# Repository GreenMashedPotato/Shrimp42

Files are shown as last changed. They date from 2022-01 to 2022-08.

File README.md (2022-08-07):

# Shrimp42(previously Kibod-01) Work In Progress

it's a keyboard inspired by [Slepet](https://github.com/ibnuda/Slepet) that has more stagger in some columns and only 3 thumb cluster keys instead of 5.

## Rev 1 (initial prototype)
Non Mirrored Keyboard uses 1 pro micro with 2x5 10pin IDC Connector:
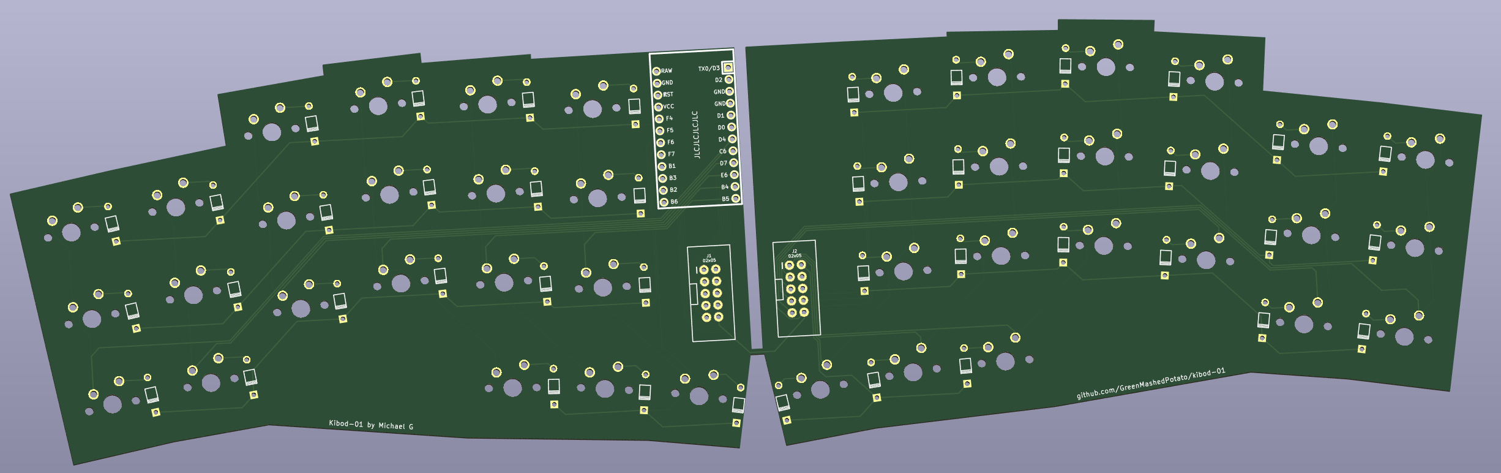
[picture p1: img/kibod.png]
kibod

 
Mirrored Keyboard, supports using 2 pro micros with trrs, or 1 pro micro with 2x5 10pin IDC Connector:
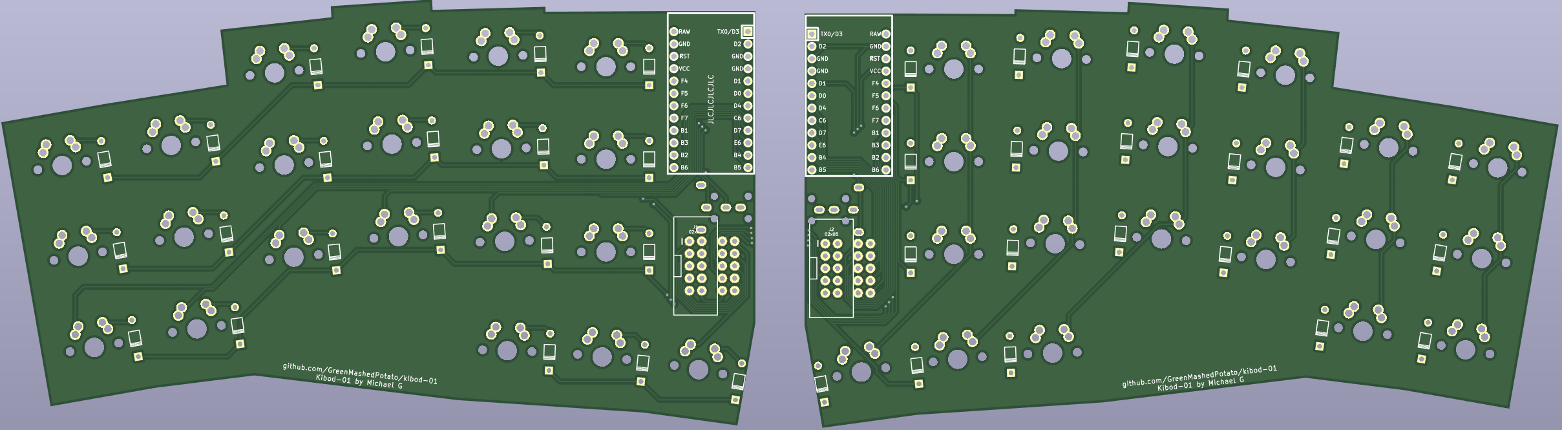
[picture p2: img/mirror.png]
mirror

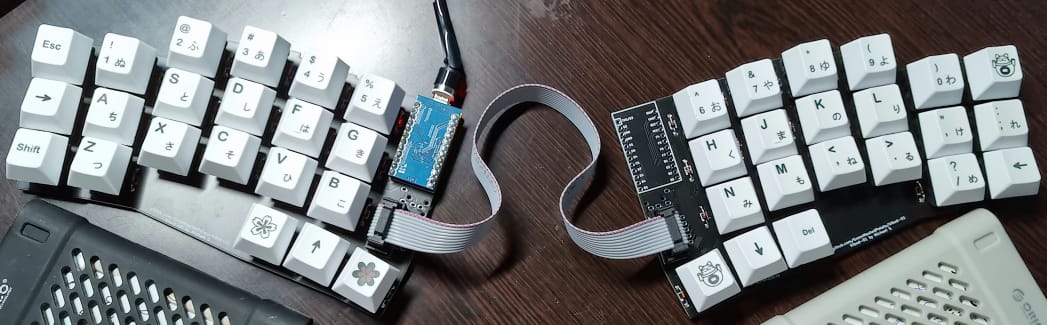
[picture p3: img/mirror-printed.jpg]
mirror


## Rev 2
Mirrored Keyboard Rev2(renamed to Shrimp42):
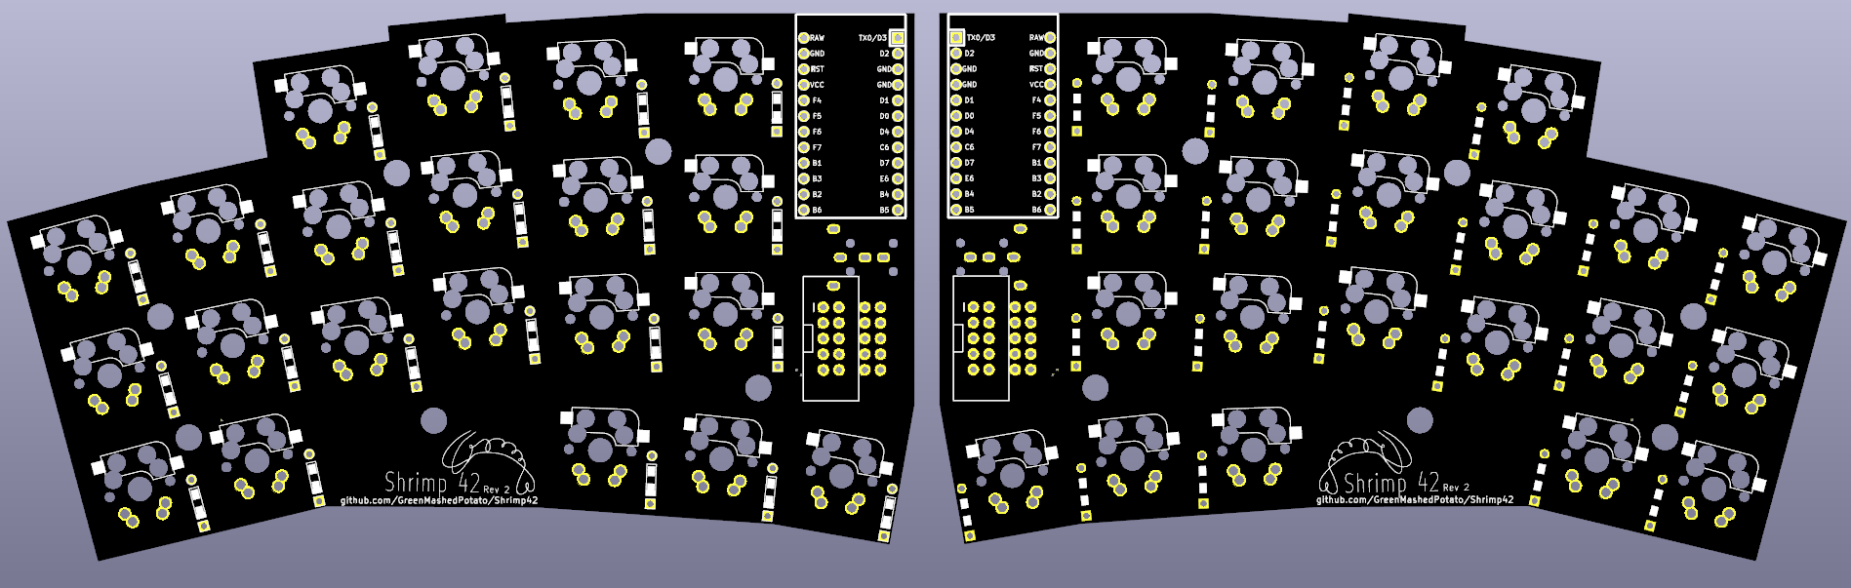
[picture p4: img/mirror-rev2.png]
mirror

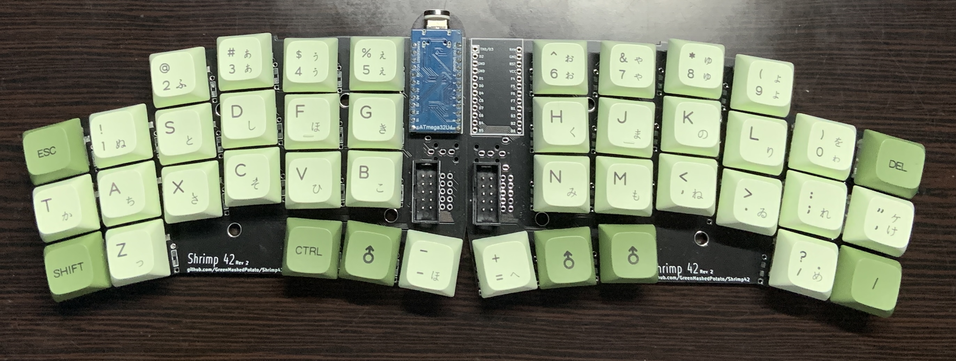
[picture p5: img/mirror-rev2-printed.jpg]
mirror

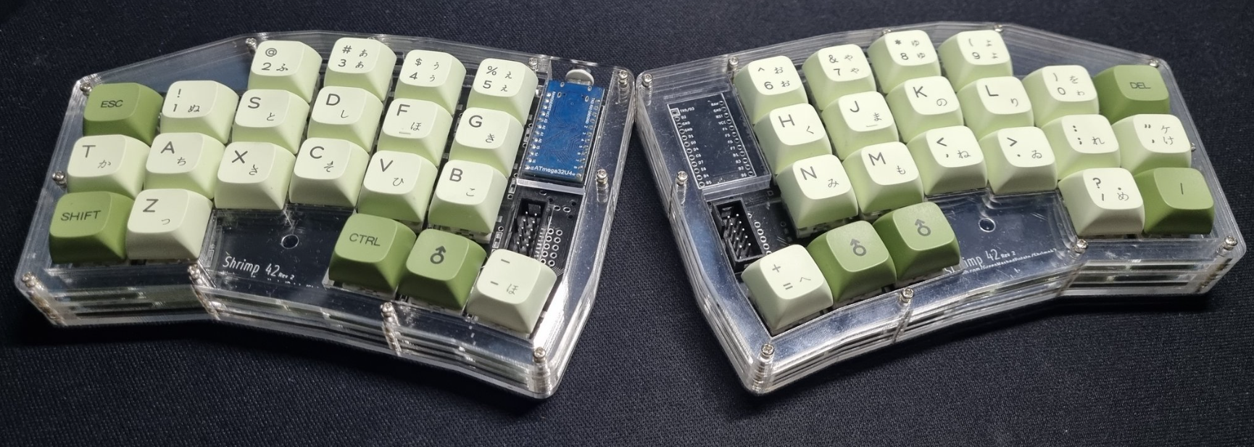
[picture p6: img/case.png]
case


improvements from rev1:

* adds support for hotswap sockets
* adds support for smd diodes
* changed angles from 2 to 3 degrees while reducing distance between columns. 
* add board name: Shrimp 42
* add Stacked Acrylic Case

V1 vs V2
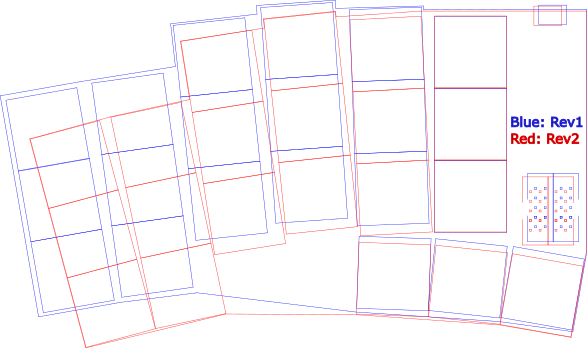
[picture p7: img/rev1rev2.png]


## Materials

| Qnty | Ref | Value | Description |
| --- | --- | --- | --- |
| 1 (2 if using trrs) | U1 | Arduino Pro-Micro ATmega32U4 |
| 42 | D-0-0 - D-3-5 | 1N4148 | Diode: 1N4148 (SOD 123 or THT)|
| 42 | K-0-0 - K-3-5 | MX or ALPS Switches | 1U |
| 42 (optional) | K-0-0 - K-3-5 | MX or ALPS Hotswap Sockets | this board supports the use of hotswap sockets and soldered connections |
| 2 | U2 | TRRS connectors OR 2x5 10pin IDC Connector |
| 1 | | TRRS Cable OR 2x5 10pin IDC Cable | used to connect both halves |
| 2 | | Shrimp42 pcb |
 
## Firmware
QMK and VIAL (provided via firmware but will need to sideload json and is untested) firmware for using the keyboard like in my setup above (using the extended GPIO pin to connect both halves and only 1 pro micro). [here](https://github.com/GreenMashedPotato/vial-qmk/tree/Shrimp42/keyboards/shrimp42).
 
QMK and VIAL for trrs connection (using 2 pro micros, slave board flipped, trrs connecting both sides) [here](https://github.com/GreenMashedPotato/vial-qmk/tree/Shrimp42/keyboards/shrimp42trrs)

## Library Used
[Keebio's footprints](https://github.com/keebio/Keebio-Parts.pretty)
[Ibnuda's footprints](https://github.com/ibnuda/rick-kicad-libs)

## Contact me:
Reddit [u/greenmashedpotato](https://www.reddit.com/user/greenmashedpotato)

## Disclaimer

I don't reccomend trying rev1 since the innermost and outermost column may be too far for some hands and can be tiring to use for long durations.

I haven't printed some of it. No guarantees that they work.

If things go wrong, I won't take any responisibilities, Try at your own risk.

## Additional Notes
After using the 2 in 1 diodes footprint, it may be too hard to know the orientation.
make sure the line on the diode is facing the square hole:
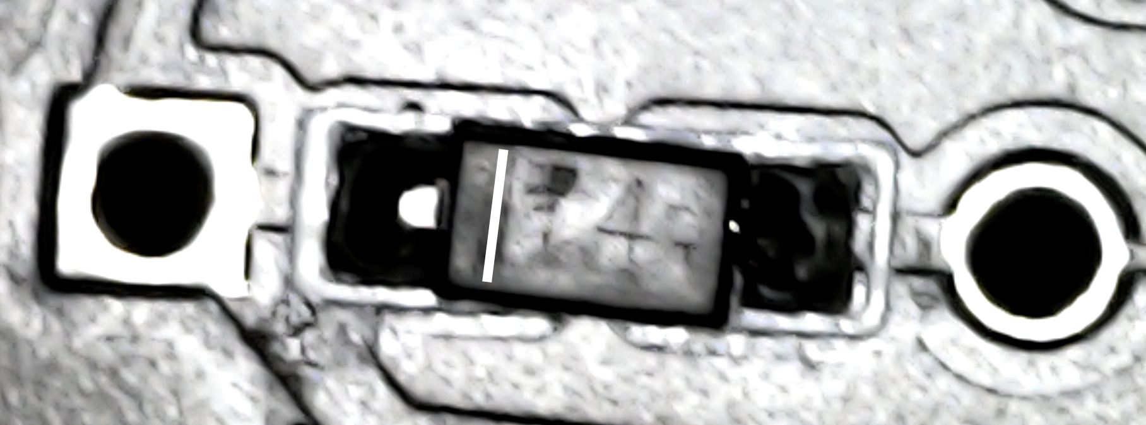
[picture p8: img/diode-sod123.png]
diode

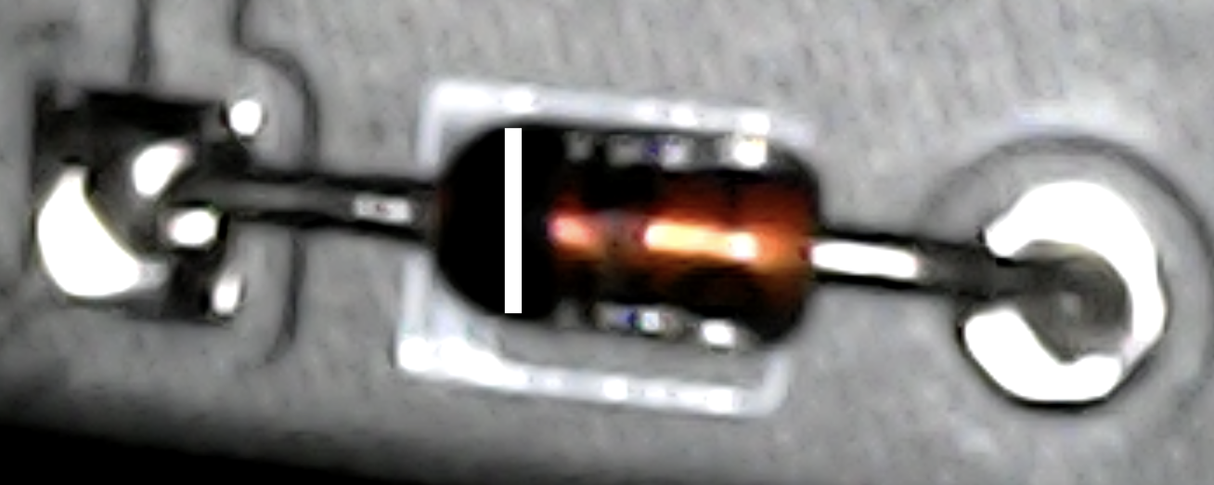
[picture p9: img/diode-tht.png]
diode


When using the Extended gpio pins to connect both halves, I have only tested using the pro micro on the left.

When using TRRS, dont forget to flip the right pro micro, I have only tested using the left pro micro as Master.

## License
GPL-3.0 License

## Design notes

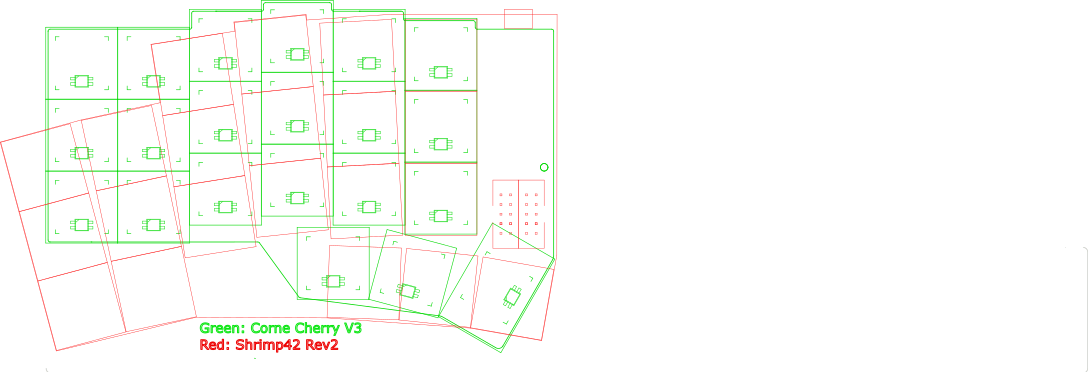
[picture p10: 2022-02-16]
img/shrimpvscorne.png

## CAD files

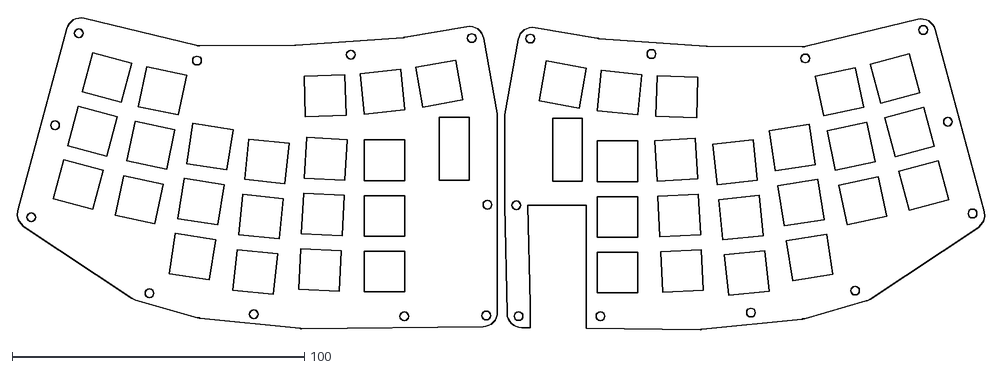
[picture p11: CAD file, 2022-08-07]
Case/Rev2/Acrylic Case/grouped by thickness/1.5mm group.dxf
331.9 x 107.2

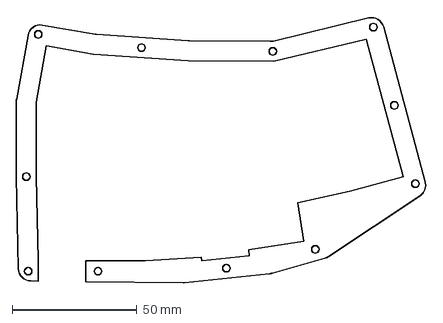
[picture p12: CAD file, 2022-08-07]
Case/Rev2/Acrylic Case/individual/middle left 2 4mm.dxf
164.7 x 106.8 mm

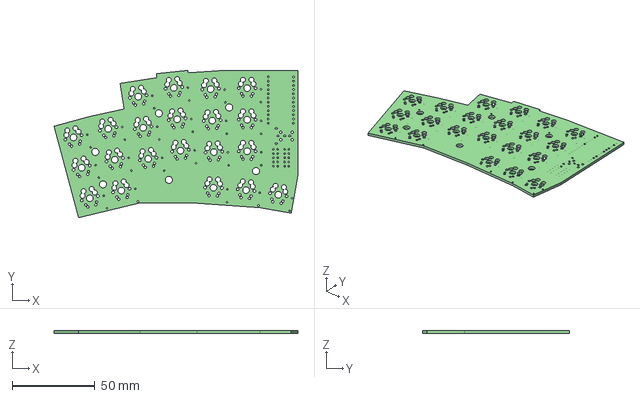
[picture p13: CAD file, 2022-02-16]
Rev2/Mirrored Rev2/kibod-01.step
147.3 x 89.0 x 1.60 mm

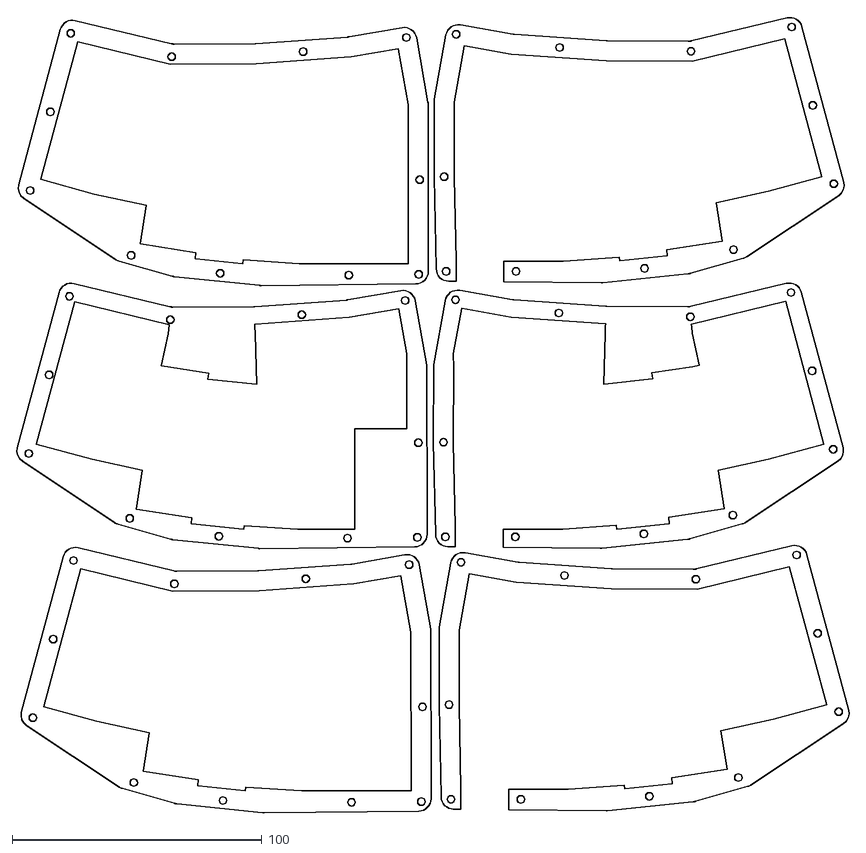
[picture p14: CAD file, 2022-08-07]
Case/Rev2/Acrylic Case/grouped by thickness/4mm group.dxf
334.3 x 319.2

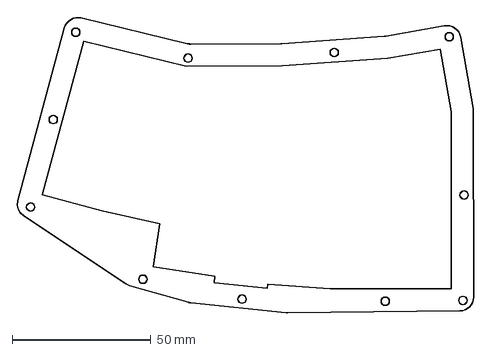
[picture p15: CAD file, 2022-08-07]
Case/Rev2/Acrylic Case/individual/middle right 4mm.dxf
164.7 x 106.8 mm

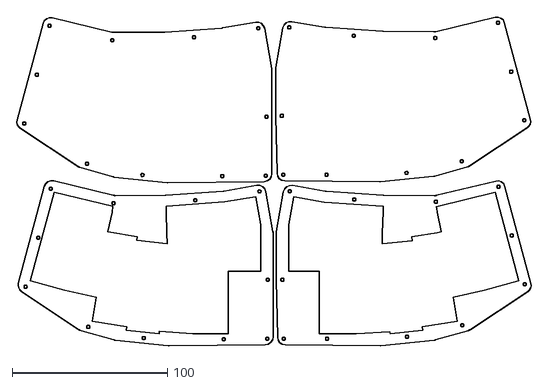
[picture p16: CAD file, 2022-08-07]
Case/Rev2/Acrylic Case/grouped by thickness/3mm group.dxf
332.3 x 212.5

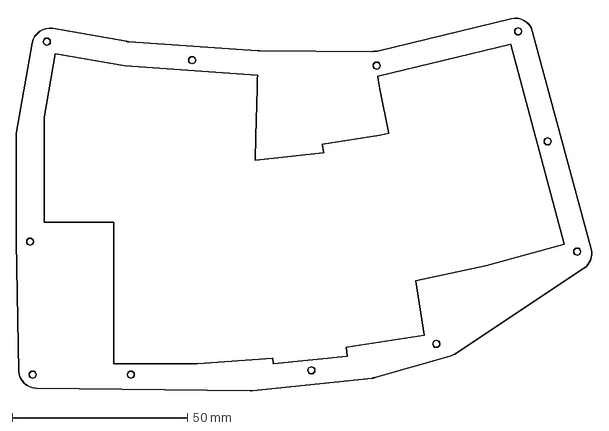
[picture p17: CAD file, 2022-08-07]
Case/Rev2/Acrylic Case/individual/top left 3mm.dxf
164.7 x 106.8 mm

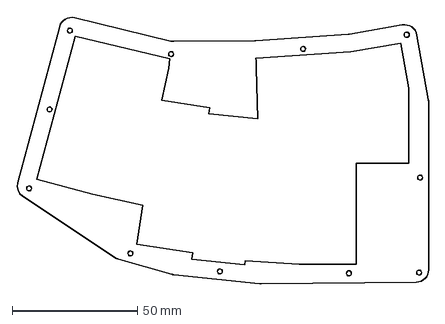
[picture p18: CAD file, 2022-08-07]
Case/Rev2/Acrylic Case/individual/top right 3mm.dxf
164.7 x 106.8 mm

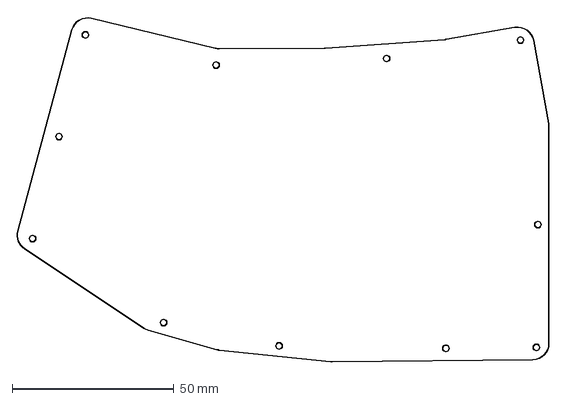
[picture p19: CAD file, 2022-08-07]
Case/Rev2/Acrylic Case/individual/bottom right 3mm.dxf
164.7 x 106.8 mm

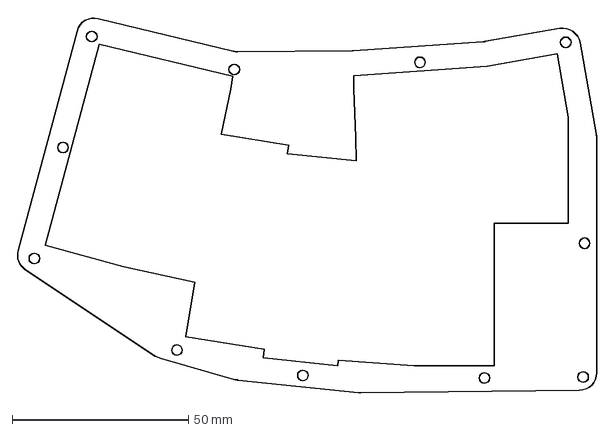
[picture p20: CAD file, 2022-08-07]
Case/Rev2/Acrylic Case/individual/second right 4mm.dxf
164.7 x 106.8 mm

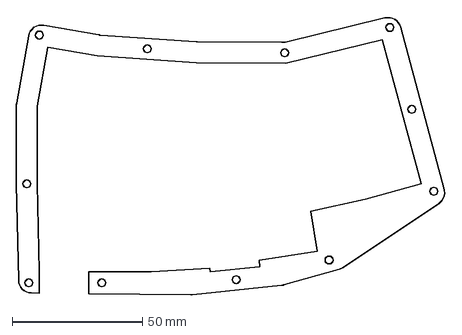
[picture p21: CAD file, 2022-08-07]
Case/Rev2/Acrylic Case/individual/middle left 4mm.dxf
164.7 x 106.8 mm

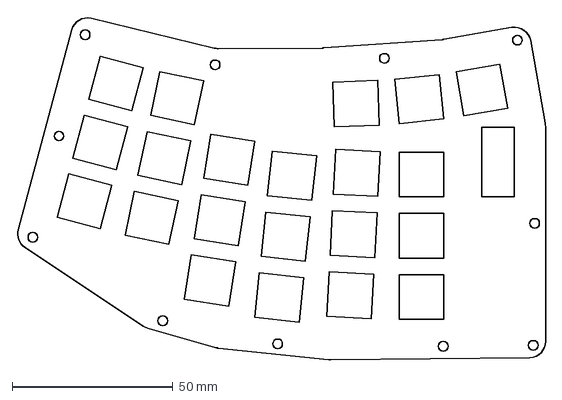
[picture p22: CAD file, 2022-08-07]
Case/Rev2/Acrylic Case/individual/plate right 1.5mm.dxf
164.7 x 106.8 mm

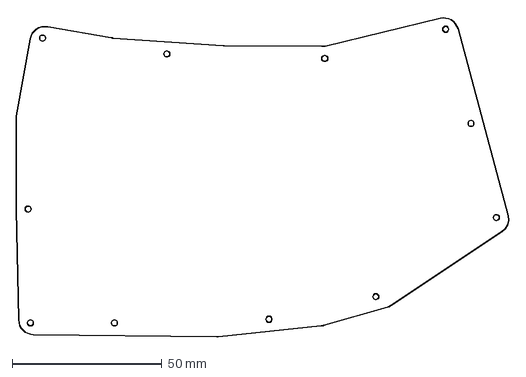
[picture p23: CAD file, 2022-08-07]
Case/Rev2/Acrylic Case/individual/bottom left 3mm.dxf
164.7 x 106.8 mm

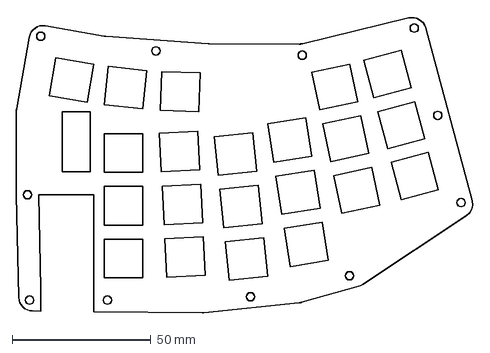
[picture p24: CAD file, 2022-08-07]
Case/Rev2/Acrylic Case/individual/plate left 1.5mm.dxf
164.7 x 106.8 mm

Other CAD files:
Case/Rev2/Acrylic Case/individual/second left 4mm.dxf
Case/Rev2/Acrylic Case/individual/middle right 2 4mm.dxf
Rev1/Mirrored Rev1/kibod-01-mirrored.step
Rev1/non-mirrored Rev1/kibod-01.step

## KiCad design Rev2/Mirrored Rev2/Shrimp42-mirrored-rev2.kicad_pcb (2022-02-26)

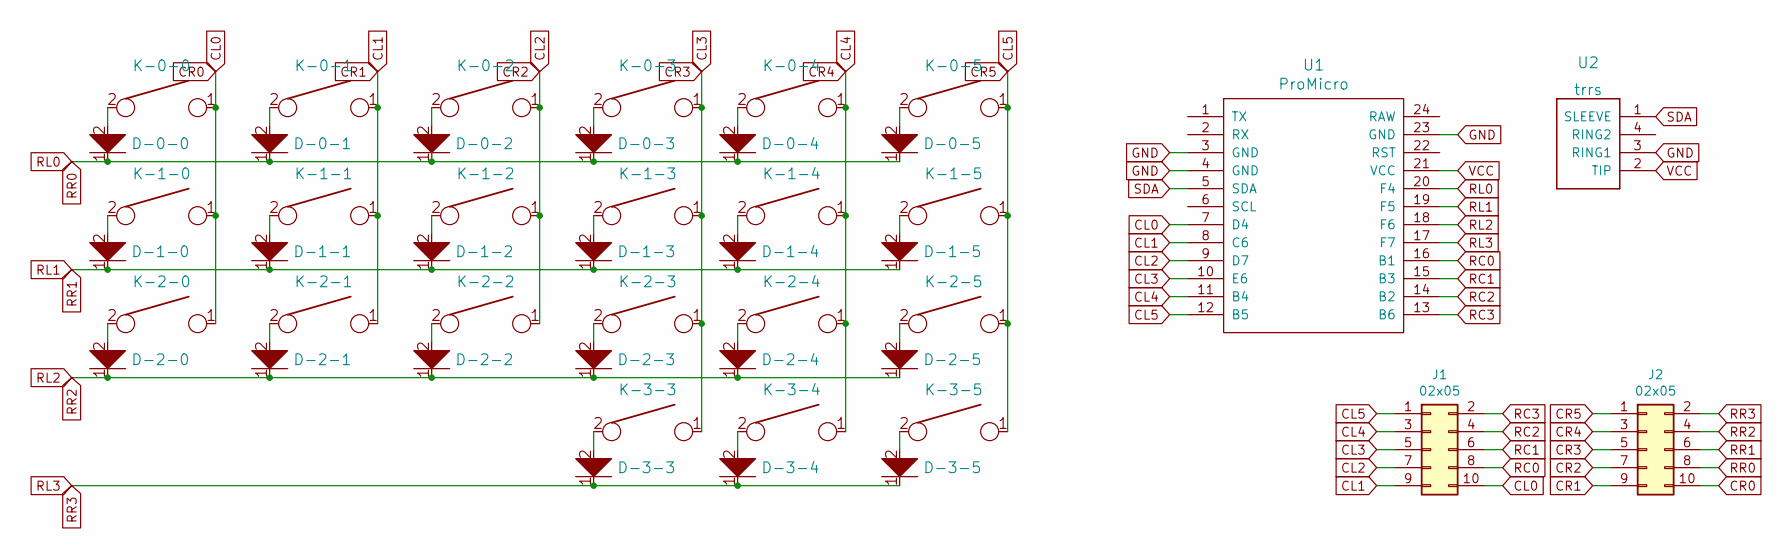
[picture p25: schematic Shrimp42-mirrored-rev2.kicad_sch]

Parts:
D-0-0, D-0-1, D-0-2, D-0-3, D-0-4, D-0-5, D-1-0, D-1-1, D-1-2, D-1-3, D-1-4, D-1-5, D-2-0, D-2-1, D-2-2, D-2-3, D-2-4, D-2-5, D-3-3, D-3-4, D-3-5: D; Diode-dual
J1, J2: 02x05; connector-shrouded
K-0-0, K-0-1, K-0-2, K-0-3, K-0-4, K-0-5, K-1-0, K-1-1, K-1-2, K-1-3, K-1-4, K-1-5, K-2-0, K-2-1, K-2-2, K-2-3, K-2-4, K-2-5, K-3-3, K-3-4, K-3-5: KEYSW; 100-dual-socket
U1: ProMicro; promicro
U2: trrs

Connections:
CL0: J1.10, J2.10, K-0-0.1, K-1-0.1, K-2-0.1, U1.7 (D4)
CL1: J1.9, J2.9, K-0-1.1, K-1-1.1, K-2-1.1, U1.8 (C6)
CL2: J1.7, J2.7, K-0-2.1, K-1-2.1, K-2-2.1, U1.9 (D7)
CL3: J1.5, J2.5, K-0-3.1, K-1-3.1, K-2-3.1, K-3-3.1, U1.10 (E6)
CL4: J1.3, J2.3, K-0-4.1, K-1-4.1, K-2-4.1, K-3-4.1, U1.11 (B4)
CL5: J1.1, J2.1, K-0-5.1, K-1-5.1, K-2-5.1, K-3-5.1, U1.12 (B5)
GND: U1.3 (GND), U1.4 (GND), U1.23 (GND), U2.3 (RING1)
unnamed: D-0-0.2, K-0-0.2
unnamed: D-0-1.2, K-0-1.2
unnamed: D-0-2.2, K-0-2.2
unnamed: D-0-3.2, K-0-3.2
unnamed: D-0-4.2, K-0-4.2
unnamed: D-0-5.2, K-0-5.2
unnamed: D-1-0.2, K-1-0.2
unnamed: D-1-1.2, K-1-1.2
unnamed: D-1-2.2, K-1-2.2
unnamed: D-1-3.2, K-1-3.2
unnamed: D-1-4.2, K-1-4.2
unnamed: D-1-5.2, K-1-5.2
unnamed: D-2-0.2, K-2-0.2
unnamed: D-2-1.2, K-2-1.2
unnamed: D-2-2.2, K-2-2.2
unnamed: D-2-3.2, K-2-3.2
unnamed: D-2-4.2, K-2-4.2
unnamed: D-2-5.2, K-2-5.2
unnamed: D-3-3.2, K-3-3.2
unnamed: D-3-4.2, K-3-4.2
unnamed: D-3-5.2, K-3-5.2
RC0: J1.8, U1.16 (B1)
RC1: J1.6, U1.15 (B3)
RC2: J1.4, U1.14 (B2)
RC3: J1.2, U1.13 (B6)
RL0: D-0-0.1, D-0-1.1, D-0-2.1, D-0-3.1, D-0-4.1, D-0-5.1, J2.8, U1.20 (F4)
RL1: D-1-0.1, D-1-1.1, D-1-2.1, D-1-3.1, D-1-4.1, D-1-5.1, J2.6, U1.19 (F5)
RL2: D-2-0.1, D-2-1.1, D-2-2.1, D-2-3.1, D-2-4.1, D-2-5.1, J2.4, U1.18 (F6)
RL3: D-3-3.1, D-3-4.1, D-3-5.1, J2.2, U1.17 (F7)
SDA: U1.5 (SDA), U2.1 (SLEEVE)
VCC: U1.21 (VCC), U2.2 (TIP)

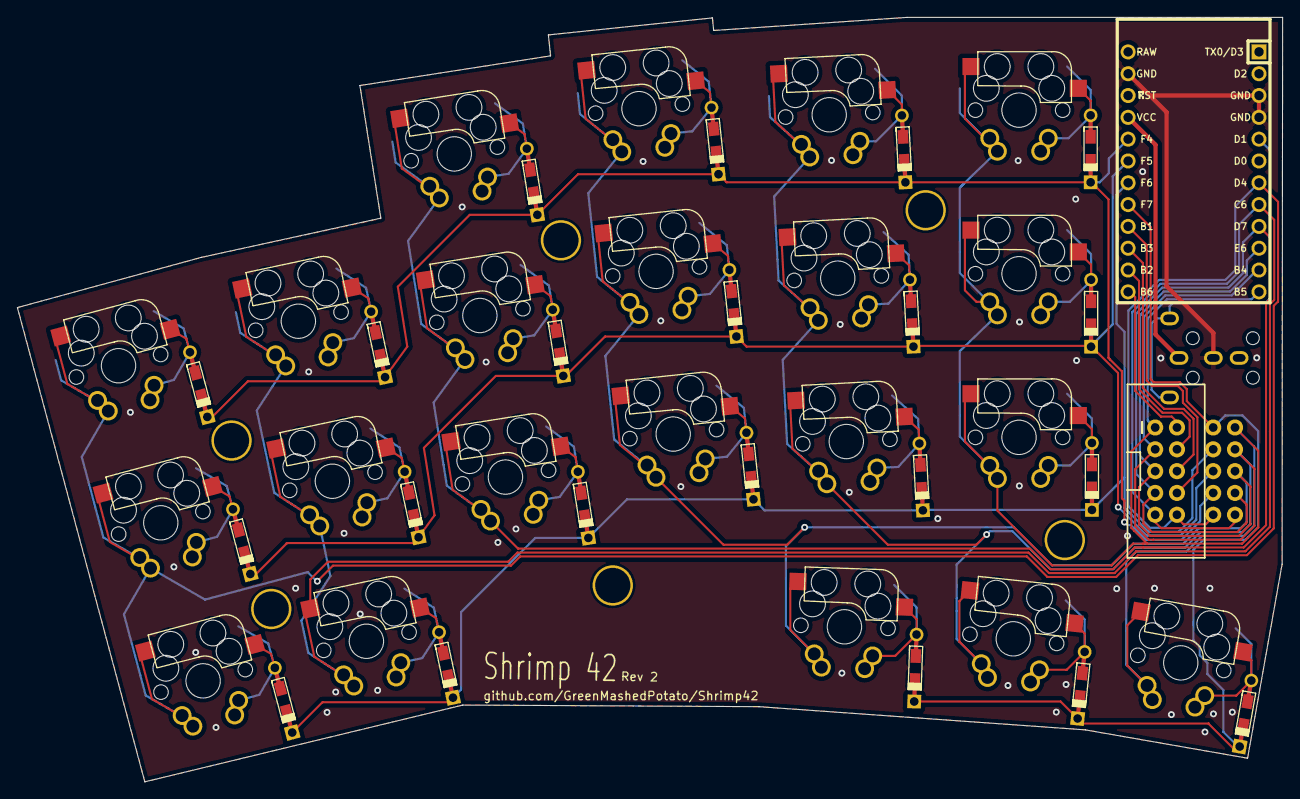
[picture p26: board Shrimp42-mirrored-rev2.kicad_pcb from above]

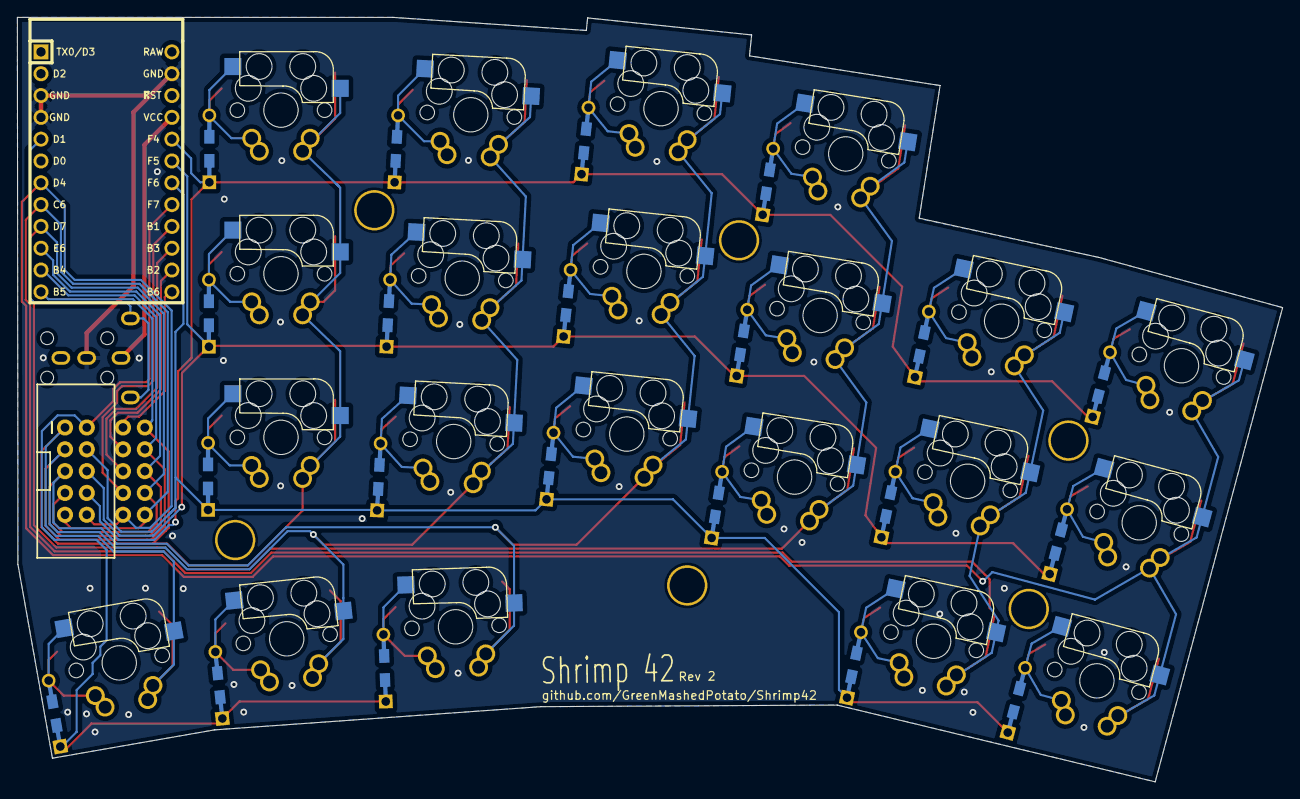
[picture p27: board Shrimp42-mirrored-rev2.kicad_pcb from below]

Board: 2 copper layers, 147.3 x 89.0 mm, 52 parts (2 on the bottom side), 38 nets.

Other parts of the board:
Ref**1, Ref**2, Ref**3, Ref**4, Ref**5, Ref**6: Val**; HOLE_M2_TH

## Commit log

2022-01-05 First Design
    [kibod-01.kicad_pcb, kibod-01.kicad_sch, kibod-01.sch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]
2022-01-05 add gerber
    [kibod-01-B_Adhesive.gbr, kibod-01-B_Courtyard.gbr, kibod-01-B_Cu.gbr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]
2022-01-05 fix outline issue
    [kibod-01-B_Adhesive.gbr, kibod-01-B_Courtyard.gbr, kibod-01-B_Cu.gbr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]
2022-01-05 add copper layer
    [kibod-01.kicad_pcb]
2022-01-05 fix minor issues
    [kibod-01-B_Adhesive.gbr, kibod-01-B_Courtyard.gbr, kibod-01-B_Cu.gbr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]
2022-01-05 move files to default folder
    [kibod-01-B_Adhesive.gbr, kibod-01-B_Courtyard.gbr, kibod-01-B_Cu.gbr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]
2022-01-05 add mirrored
    [kibod-01-B_Adhesive.gbr, kibod-01-B_Courtyard.gbr, kibod-01-B_Cu.gbl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]
2022-01-05 fix gerber error jlcpcb
    [kibod-01-B_Courtyard.gbr, kibod-01-B_Cu.gbl, kibod-01-B_Fab.gbr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]
2022-01-17 renamed mirrored
    [kibod-01-mirrored.kicad_pcb, kibod-01-mirrored.kicad_sch, kibod-01-mirrored.sch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]
2022-01-25 fixed non reversible holes
    [kibod-01-B_Courtyard.gbr, kibod-01-B_Cu.gbl, kibod-01-B_Fab.gbr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]
2022-01-29 update gerber and readme
    [kibod-01-B_Mask.gbs, kibod-01-F_Mask.gts, kibod-01-User_Drawings.gbr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]
2022-01-29 removed case svg, will readd after fixing it.
2022-02-04 add rev2
    [kibod-01-mirrored-rev2-B_Courtyard.gbr, kibod-01-mirrored-rev2-B_Cu.gbl, kibod-01-mirrored-rev2-B_Fab.gbr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]
2022-02-05 add name and icon, add mounting holes, add trrs support back
    [kibod-01-mirrored-rev2-B_Courtyard.gbr, kibod-01-mirrored-rev2-B_Cu.gbl, kibod-01-mirrored-rev2-B_Fab.gbr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]
2022-02-05 cleanup some wiring
    [kibod-01-mirrored-rev2-B_Courtyard.gbr, kibod-01-mirrored-rev2-B_Cu.gbl, kibod-01-mirrored-rev2-B_Fab.gbr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]
2022-02-06 update readme, update wiring
    [kibod-01-mirrored-rev2-B_Courtyard.gbr, kibod-01-mirrored-rev2-B_Cu.gbl, kibod-01-mirrored-rev2-B_Fab.gbr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]
2022-02-06 add support for smd diodes
    [kibod-01-mirrored-rev2-B_Courtyard.gbr, kibod-01-mirrored-rev2-B_Cu.gbl, kibod-01-mirrored-rev2-B_Fab.gbr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]
2022-02-07 fixed and straightened some wirings
    [kibod-01-mirrored-rev2-B_Courtyard.gbr, kibod-01-mirrored-rev2-B_Cu.gbl, kibod-01-mirrored-rev2-B_Fab.gbr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]
2022-02-08 added case, update readme
    [PCB Bottom-B_Cu.gbl, PCB Bottom-B_Mask.gbs, PCB Bottom-B_Paste.gbp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]
2022-02-09 restructure repo
    [Shrimp42-mirrored-rev2.kicad_pcb, Shrimp42-mirrored-rev2.kicad_sch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]
2022-02-11 update shrimp image to be smaller
    [Shrimp42-mirrored-rev2-B_Courtyard.gbr, Shrimp42-mirrored-rev2-B_Cu.gbl, Shrimp42-mirrored-rev2-B_Fab.gbr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]
2022-02-12 update thumb cluster since its too close to amphenol cutout
    [PCB Bottom-B_Cu.gbl, PCB Bottom-B_Mask.gbs, PCB Bottom-B_Paste.gbp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]
2022-02-16 update readme, update icon
    [Shrimp42-mirrored-rev2-B_Courtyard.gbr, Shrimp42-mirrored-rev2-B_Cu.gbl, Shrimp42-mirrored-rev2-B_Fab.gbr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]
2022-02-26 rewired board. change pcb holes. push commit before order pcb
    [Shrimp42-mirrored-rev2-B_Courtyard.gbr, Shrimp42-mirrored-rev2-B_Cu.gbl, Shrimp42-mirrored-rev2-B_Fab.gbr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]
2022-08-07 add acrylic case
    [1.5mm group.dxf, 3mm group.dxf, 4mm group.dxf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]
